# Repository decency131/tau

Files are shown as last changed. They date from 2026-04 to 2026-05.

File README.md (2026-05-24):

# tau



tau is a pedal that converts musical instrument input into USB MIDI notes.

It is based on [daisy seed by Electrosmith](https://daisy.audio/hardware/Seed/) and [daisy-embassy](https://github.com/daisy-embassy/daisy-embassy) (which is based on [embassy](https://embassy.dev/), an embedded async runtime).

Current main branch contains firmware for the first revision hardware. Firmware for the second revision can be found on the [rev2-attempt branch](https://github.com/decency131/tau/tree/rev2-attempt) and is mostly finished, apart from optimization work currently present on the main branch. Second revision hardware needs some adjustments and fixes that are planned to be implemented in the future.

## Current features 

- Real-time pitch detection from instrument input
- USB MIDI output
- MIDI note on/off generation based on detected pitch
- Channel selection using an expression pedal
- Basic MIDI looper functionality
- Footswitch control:
  - SW1: record / play / overdub
  - SW2 short press: pause / resume
  - SW2 long press: clear loop
- Channel indicator LEDs

## How it works

The audio input is received from the Daisy Seed audio codec. Audio frames are copied from the audio callback into a separate pitch detection task, so heavier DSP work does not run directly inside the audio callback.

Pitch detection is done using a [no-std YIN implementation](https://github.com/decency131/yin-no_std). Detected frequencies are converted to MIDI notes. A small smoothing layer is used to reduce note flicker and avoid fast retriggering when the detected note is unstable.

MIDI events are sent over USB MIDI. The looper records MIDI events together with their timing and MIDI channel, so previously recorded loops keep playing on the original channel even if the expression pedal changes the current channel later.

## Build
```zsh
cargo build --features=seed_1_2 --release
```
Adjust to your seed revision.

## Flash/run

The recommended way is to use a debug probe (such as ST-LINK v3 minie), and run
```zsh 
cargo run --features=seed_1_2 --release
```
or 
```zsh 
DEFMT_LOG=warn cargo run --features=seed_1_2 --release
```
for less logging overhead.

Electrosmith have, however, recently [made their bootloader open source](https://github.com/electro-smith/DaisyBootloader), so you could try using that, or their [online flasher](https://flash.daisy.audio/).

> [!NOTE]
> This project is released under the **WTFPL** license.

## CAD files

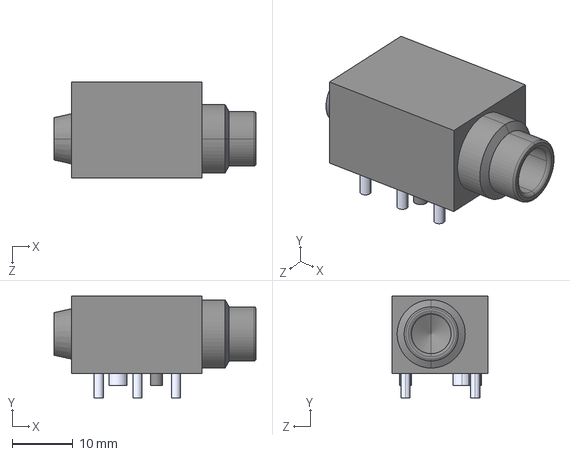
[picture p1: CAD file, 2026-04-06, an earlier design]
hw/tau_v1/3d models/NRJ6HH--3DModel-STEP-510211.STEP
33.2 x 16.7 x 15.8 mm

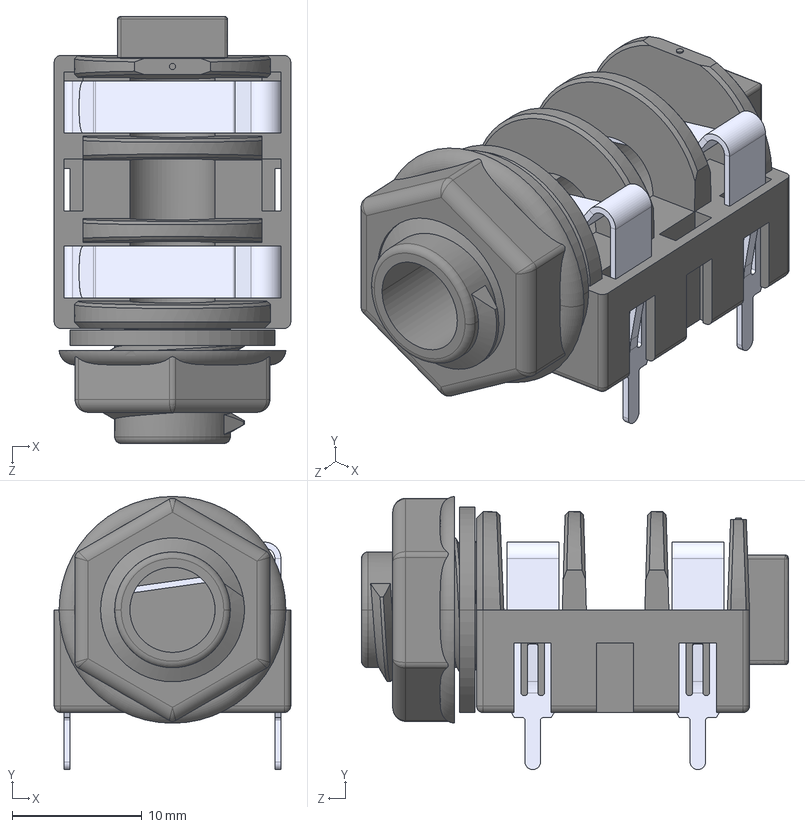
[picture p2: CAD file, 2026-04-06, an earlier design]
hw/tau_v1/3d models/NMJ4HFD2--3DModel-STEP-56544.STEP
18.2 x 21.0 x 32.9 mm

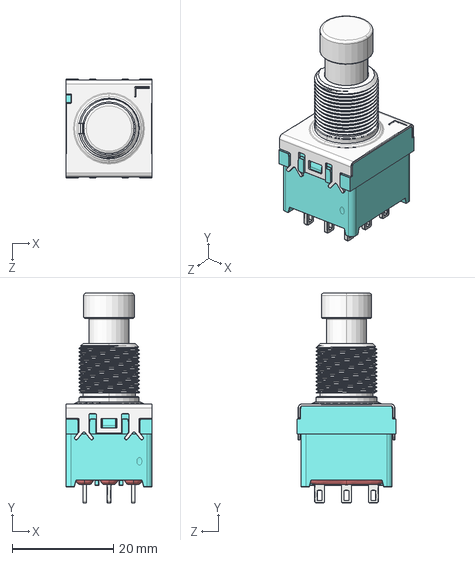
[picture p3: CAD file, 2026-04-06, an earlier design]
hw/tau_v1/3d models/3PDT_FOOTSWITCH.STEP
17.1 x 41.5 x 19.6 mm

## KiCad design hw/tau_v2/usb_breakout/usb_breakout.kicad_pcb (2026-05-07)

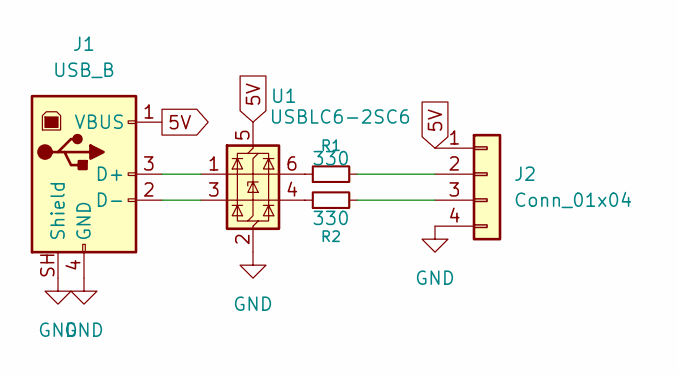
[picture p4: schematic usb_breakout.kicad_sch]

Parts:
J1: USB_B; USB_B_OST_USB-B1HSxx_Horizontal
J2: Conn_01x04; PinHeader_1x04_P2.00mm_Vertical
R1, R2: 330; R_0805_2012Metric_Pad1.20x1.40mm_HandSolder
U1: USBLC6-2SC6; SOT-23-6

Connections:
5V: J1.1 (VBUS), J2.1, U1.5 (VBUS)
GND: J1.4 (GND), J1.SH (Shield), J2.4, U1.2 (GND)
unnamed: J1.3 (D+), U1.1 (I/O1)
unnamed: J1.2 (D-), U1.3 (I/O2)
unnamed: J2.2, R1.2
unnamed: J2.3, R2.2
unnamed: R1.1, U1.6 (I/O1)
unnamed: R2.1, U1.4 (I/O2)

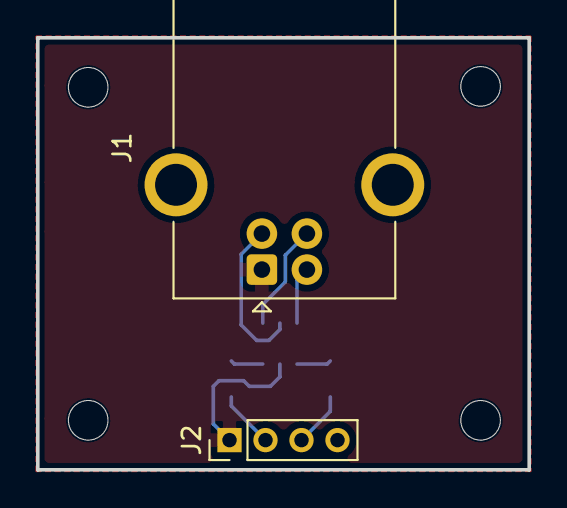
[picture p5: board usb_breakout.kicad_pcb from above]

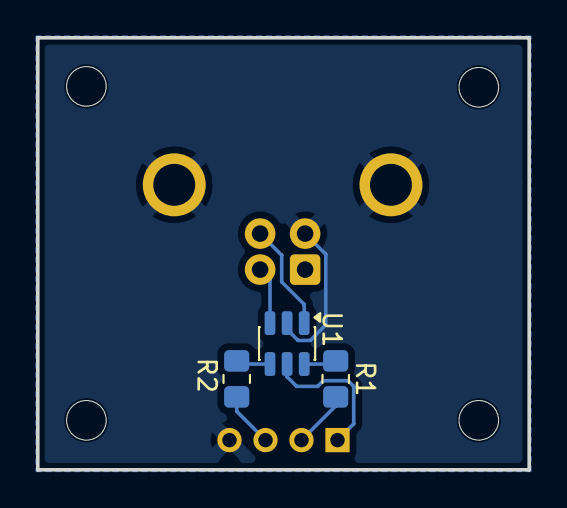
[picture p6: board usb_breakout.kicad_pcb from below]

Board: 2 copper layers, 27.3 x 24.0 mm, 9 parts (3 on the bottom side), 8 nets.

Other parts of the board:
M1, M2, M3, M4: MountingHole_2.2mm_M2

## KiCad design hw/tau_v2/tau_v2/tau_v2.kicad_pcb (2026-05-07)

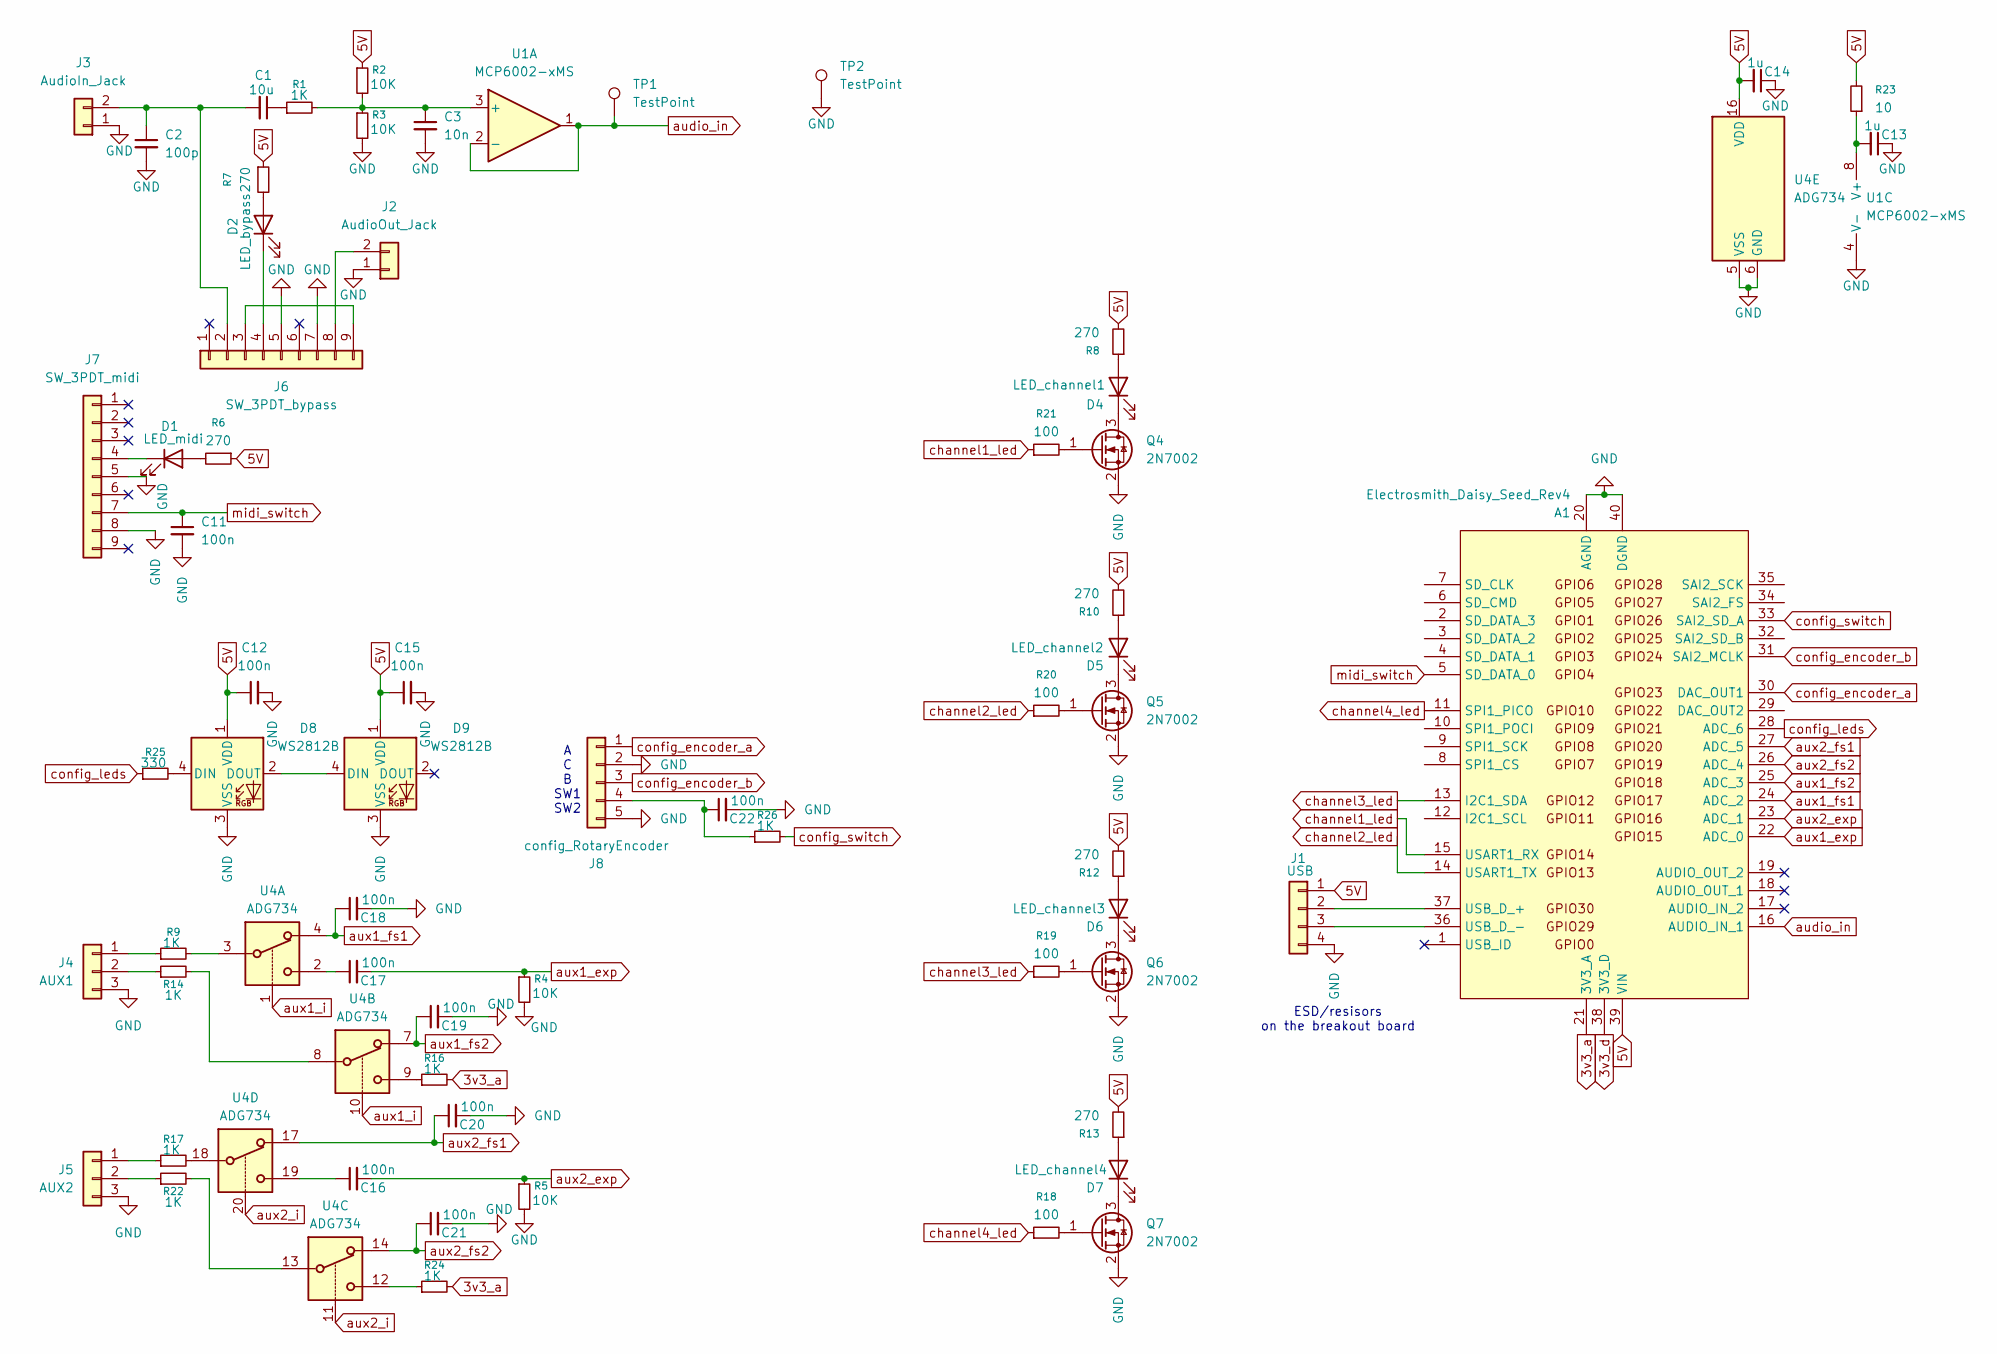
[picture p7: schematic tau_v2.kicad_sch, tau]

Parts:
A1: Electrosmith_Daisy_Seed_Rev4; Electrosmith_Daisy_Seed
C1: 10u; C_0805_2012Metric_Pad1.18x1.45mm_HandSolder
C2: 100p; C_0805_2012Metric_Pad1.18x1.45mm_HandSolder
C3: 10n; C_0805_2012Metric_Pad1.18x1.45mm_HandSolder
C11, C12, C15, C16, C17, C18, C19, C20, C21, C22: 100n; C_0805_2012Metric_Pad1.18x1.45mm_HandSolder
C13, C14: 1u; C_0805_2012Metric_Pad1.18x1.45mm_HandSolder
D1: LED_midi; PinHeader_1x02_P2.00mm_Vertical
D2: LED_bypass; PinHeader_1x02_P2.00mm_Vertical
D4: LED_channel1; PinHeader_1x02_P2.00mm_Vertical
D5: LED_channel2; PinHeader_1x02_P2.00mm_Vertical
D6: LED_channel3; PinHeader_1x02_P2.00mm_Vertical
D7: LED_channel4; PinHeader_1x02_P2.00mm_Vertical
D8, D9: WS2812B; PinHeader_1x04_P2.00mm_Vertical
J1: USB; PinHeader_1x04_P2.00mm_Vertical
J2: AudioOut_Jack; PinHeader_1x02_P2.00mm_Vertical
J3: AudioIn_Jack; PinHeader_1x02_P2.00mm_Vertical
J4: AUX1; PinHeader_1x03_P2.00mm_Vertical
J5: AUX2; PinHeader_1x03_P2.00mm_Vertical
J6: SW_3PDT_bypass; PinHeader_1x09_P2.00mm_Vertical
J7: SW_3PDT_midi; PinHeader_1x09_P2.00mm_Vertical
J8: config_RotaryEncoder; PinHeader_1x05_P2.00mm_Vertical
Q4, Q5, Q6, Q7: 2N7002; SOT-23
R1, R9, R14, R16, R17, R22, R24, R26: 1K; R_0805_2012Metric_Pad1.20x1.40mm_HandSolder
R2, R3, R4, R5: 10K; R_0805_2012Metric_Pad1.20x1.40mm_HandSolder
R6, R7, R8, R10, R12, R13: 270; R_0805_2012Metric_Pad1.20x1.40mm_HandSolder
R18, R19, R20, R21: 100; R_0805_2012Metric_Pad1.20x1.40mm_HandSolder
R23: 10; R_0805_2012Metric_Pad1.20x1.40mm_HandSolder
R25: 330; R_0805_2012Metric_Pad1.20x1.40mm_HandSolder
TP1, TP2: TestPoint; Pin_D1.0mm_L10.0mm_LooseFit
U1: MCP6002-xMS; MSOP-8-1EP_3x3mm_P0.65mm_EP1.5x1.8mm_handsoldered
U4: ADG734; TSSOP-20_4.4x6.5mm_P0.65mm

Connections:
3v3_a: A1.21 (3V3_A), R16.2, R24.2
3v3_d: A1.38 (3V3_D)
5V: A1.39 (VIN), C12.1, C14.2, C15.1, D8.1 (VDD), D9.1 (VDD), J1.1, R2.1, R6.1, R7.1, R8.2, R10.2, R12.2, R13.2, R23.2, U4.16 (VDD)
GND: A1.20 (AGND), A1.40 (DGND), C2.2, C3.2, C11.2, C12.2, C13.1, C14.1, C15.2, C18.2, C19.2, C20.2, C21.2, C22.2, D8.3 (VSS), D9.3 (VSS), J1.4, J2.1, J3.1, J4.3, J5.3, J6.5, J6.7, J7.5, J7.8, J8.2, J8.5, Q4.2 (S), Q5.2 (S), Q6.2 (S), Q7.2 (S), R3.2, R4.2, R5.2, TP2.1 (1_1), U1.4 (V-), U4.5 (VSS), U4.6 (GND)
unnamed: A1.37 (USB_D_+), J1.2
unnamed: A1.36 (USB_D_-), J1.3
unnamed: C1.1, R1.1
unnamed: C16.1, U4.19
unnamed: C17.1, U4.2
unnamed: D1.2 (A), R6.2
unnamed: D1.1 (K), J7.4
unnamed: D2.2 (A), R7.2
unnamed: D2.1 (K), J6.4
unnamed: D4.2 (A), R8.1
unnamed: D4.1 (K), Q4.3 (D)
unnamed: D5.2 (A), R10.1
unnamed: D5.1 (K), Q5.3 (D)
unnamed: D6.2 (A), R12.1
unnamed: D6.1 (K), Q6.3 (D)
unnamed: D7.2 (A), R13.1
unnamed: D7.1 (K), Q7.3 (D)
unnamed: D8.4 (DIN), R25.2
unnamed: D8.2 (DOUT), D9.4 (DIN)
unnamed: J2.2, J6.8
unnamed: C1.2, C2.1, J3.2, J6.2
unnamed: J4.1, R9.1
unnamed: J4.2, R14.1
unnamed: J5.1, R17.1
unnamed: J5.2, R22.1
unnamed: J6.3, J6.9
unnamed: C22.1, J8.4, R26.1
unnamed: Q4.1 (G), R21.2
unnamed: Q5.1 (G), R20.2
unnamed: Q6.1 (G), R19.2
unnamed: Q7.1 (G), R18.2
unnamed: R9.2, U4.3
unnamed: R14.2, U4.8
unnamed: R16.1, U4.9
unnamed: R17.2, U4.18
unnamed: R22.2, U4.13
unnamed: R24.1, U4.12
unnamed: C3.1, R1.2, R2.2, R3.1, U1.3 (+)
unnamed: C13.2, R23.1, U1.8 (V+)
audio_in: A1.16 (AUDIO_IN_1), TP1.1 (1_1), U1.1, U1.2 (-)
aux1_exp: A1.22 (ADC_0), C17.2, R4.1
aux1_fs1: A1.24 (ADC_2), C18.1, U4.4
aux1_fs2: A1.25 (ADC_3), C19.1, U4.7
aux1_i: U4.1, U4.10
aux2_exp: A1.23 (ADC_1), C16.2, R5.1
aux2_fs1: A1.27 (ADC_5), C20.1, U4.17
aux2_fs2: A1.26 (ADC_4), C21.1, U4.14
aux2_i: U4.11, U4.20
channel1_led: A1.15 (USART1_RX), R21.1
channel2_led: A1.14 (USART1_TX), R20.1
channel3_led: A1.13 (I2C1_SDA), R19.1
channel4_led: A1.11 (SPI1_PICO), R18.1
config_encoder_a: A1.30 (DAC_OUT1), J8.1
config_encoder_b: A1.31 (SAI2_MCLK), J8.3
config_leds: A1.28 (ADC_6), R25.1
config_switch: A1.33 (SAI2_SD_A), R26.2
midi_switch: A1.5 (SD_DATA_0), C11.1, J7.7

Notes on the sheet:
ESD/resisors on the breakout board
A C B SW1 SW2

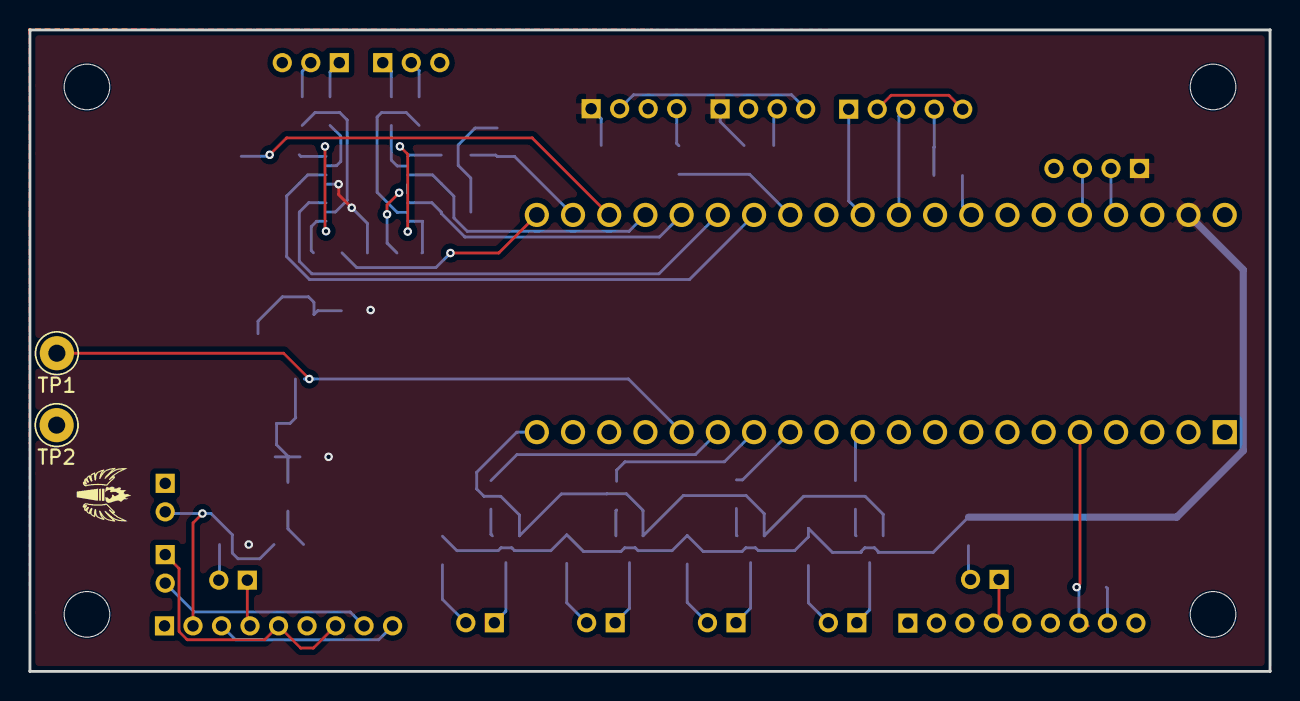
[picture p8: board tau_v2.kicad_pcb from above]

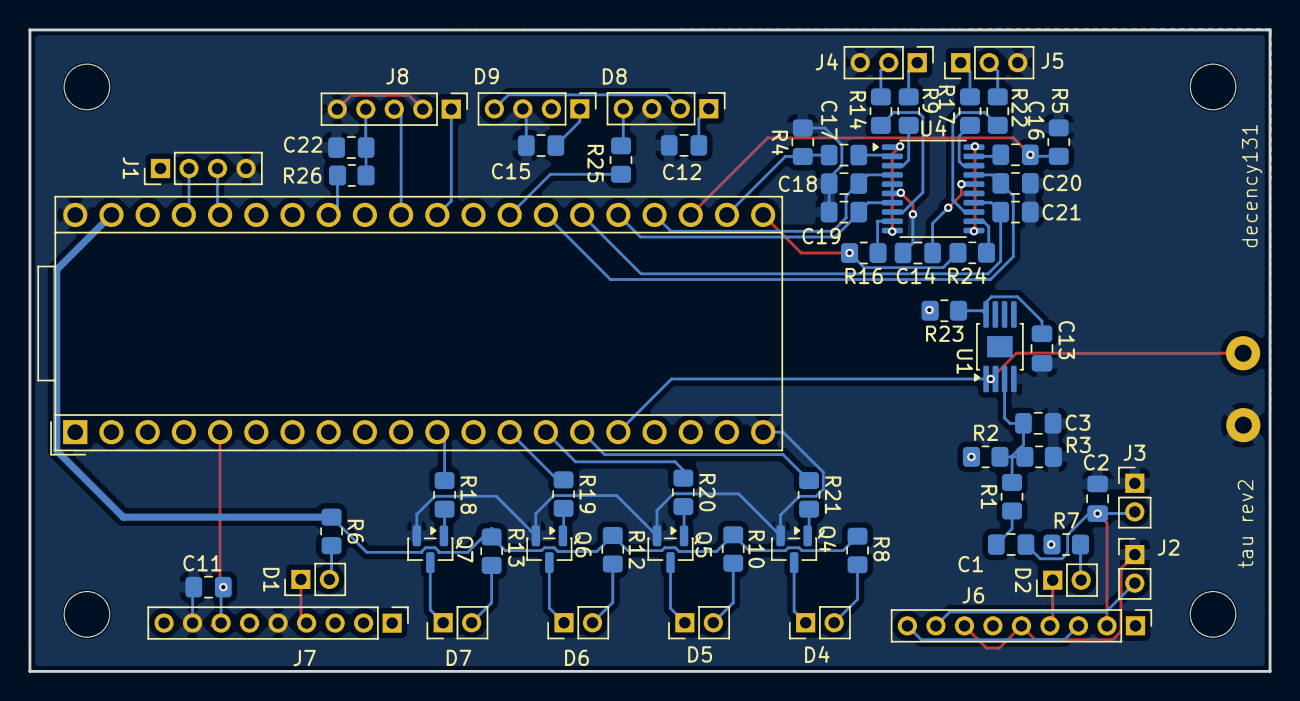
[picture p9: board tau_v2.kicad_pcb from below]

Board: 2 copper layers, 87.0 x 45.0 mm, 68 parts (62 on the bottom side), 60 nets.

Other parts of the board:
MH1, MH2, MH3, MH4: MountingHole_3.2mm_M3

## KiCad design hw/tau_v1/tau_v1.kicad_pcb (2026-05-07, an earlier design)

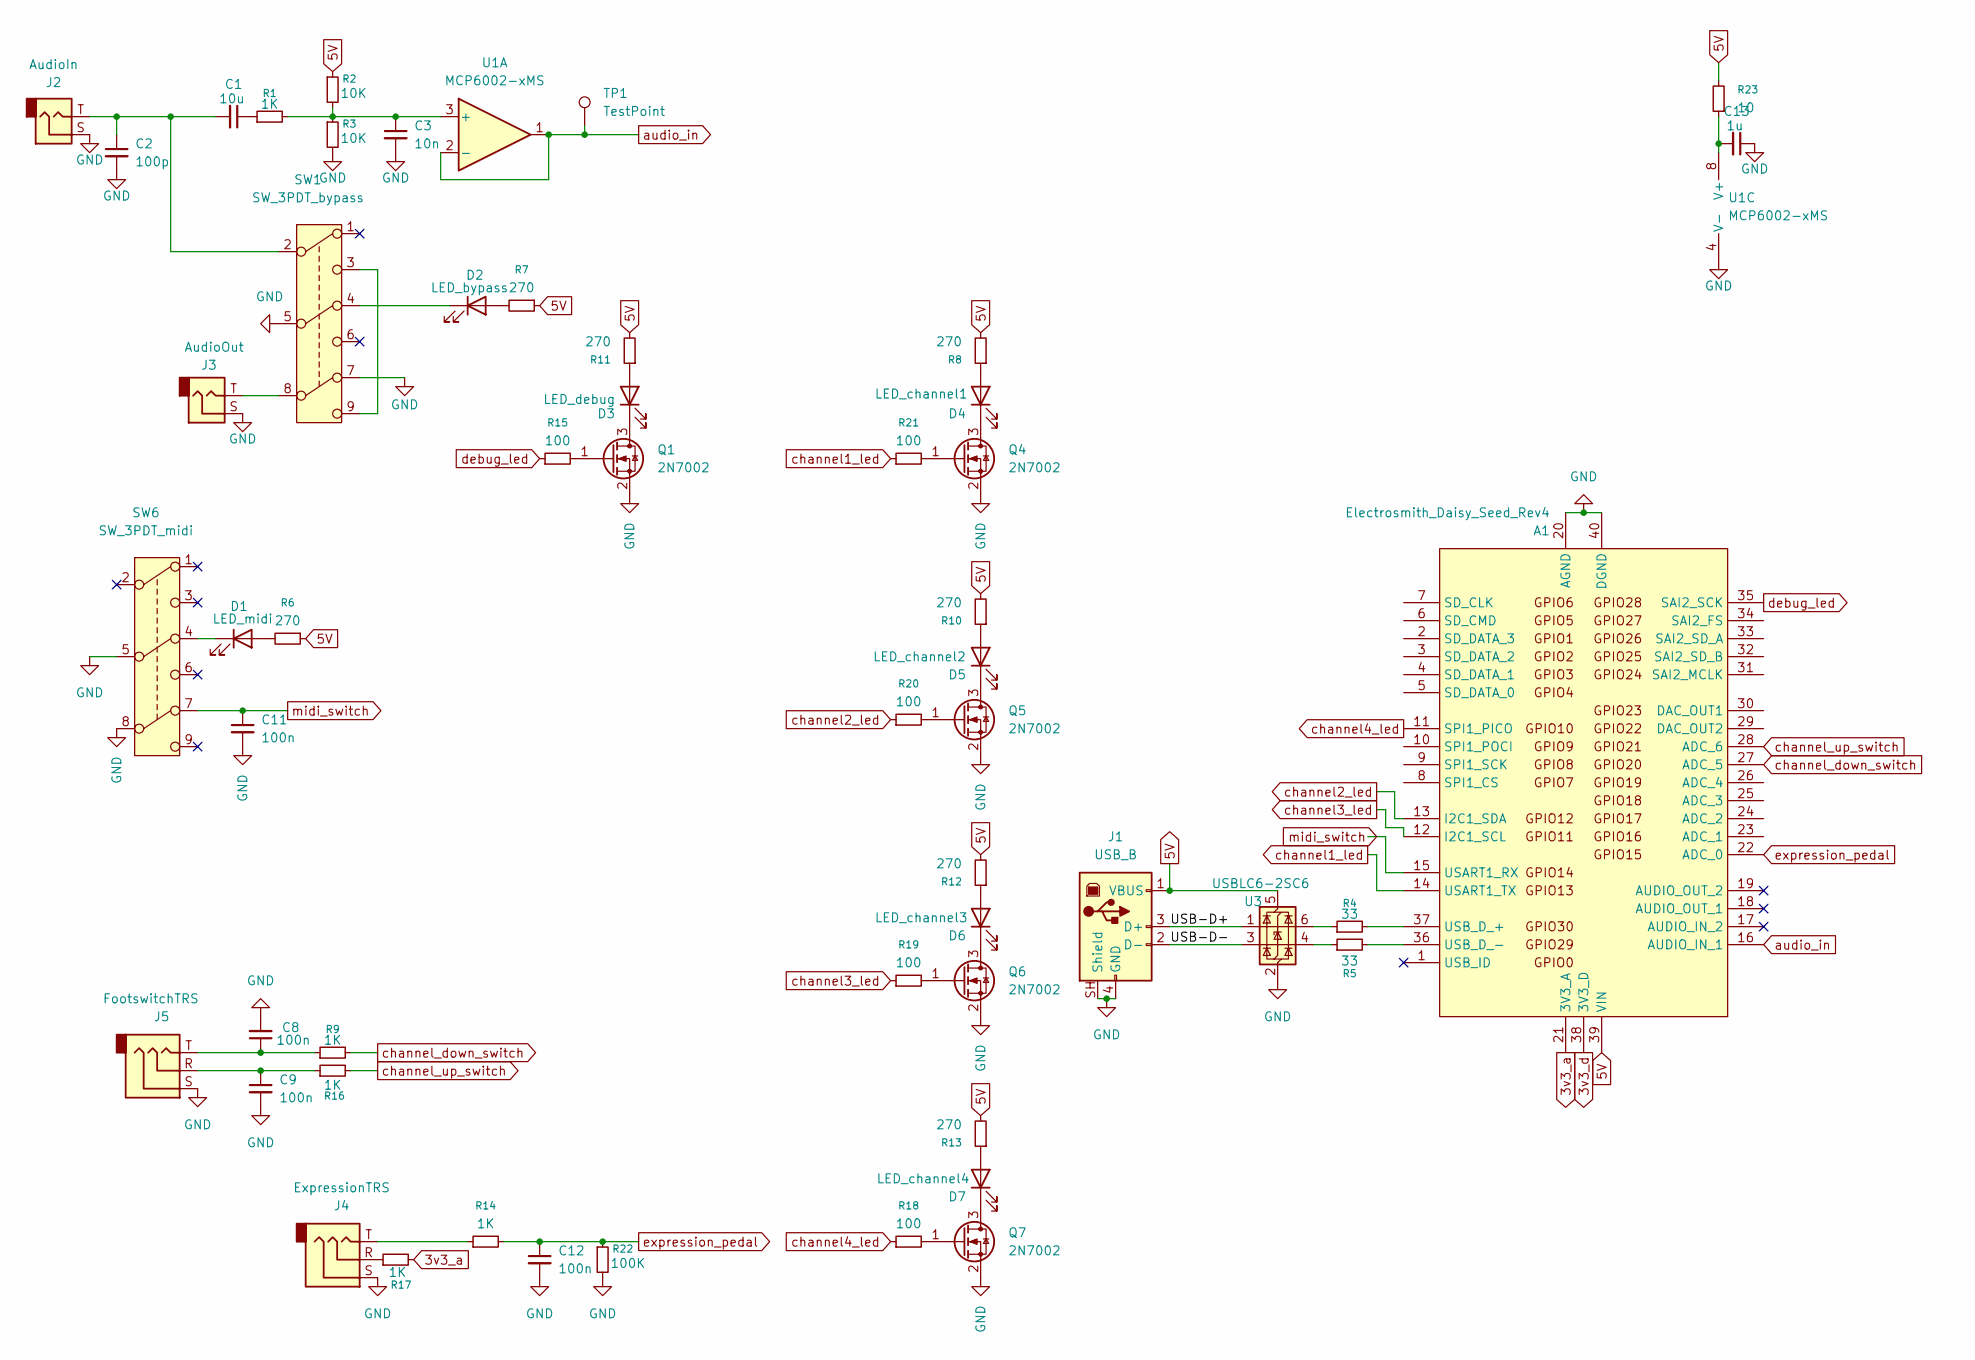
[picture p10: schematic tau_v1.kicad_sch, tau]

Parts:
A1: Electrosmith_Daisy_Seed_Rev4; Electrosmith_Daisy_Seed
C1: 10u; C_0805_2012Metric_Pad1.18x1.45mm_HandSolder
C2: 100p; C_0805_2012Metric_Pad1.18x1.45mm_HandSolder
C3: 10n; C_0805_2012Metric_Pad1.18x1.45mm_HandSolder
C8, C9, C11, C12: 100n; C_0805_2012Metric_Pad1.18x1.45mm_HandSolder
C13: 1u; C_0805_2012Metric_Pad1.18x1.45mm_HandSolder
D1: LED_midi; JST_XH_B2B-XH-A_1x02_P2.50mm_Vertical
D2: LED_bypass; JST_XH_B2B-XH-A_1x02_P2.50mm_Vertical
D3: LED_debug; LED_0805_2012Metric_Pad1.15x1.40mm_HandSolder
D4: LED_channel1; JST_XH_B2B-XH-A_1x02_P2.50mm_Vertical
D5: LED_channel2; JST_XH_B2B-XH-A_1x02_P2.50mm_Vertical
D6: LED_channel3; JST_XH_B2B-XH-A_1x02_P2.50mm_Vertical
D7: LED_channel4; JST_XH_B2B-XH-A_1x02_P2.50mm_Vertical
J1: USB_B; USB_B_OST_USB-B1HSxx_Horizontal
J2: AudioIn; Jack_6.35mm_Neutrik_NMJ4HFD2_Horizontal
J3: AudioOut; Jack_6.35mm_Neutrik_NMJ4HFD2_Horizontal
J4: ExpressionTRS; Jack_6.35mm_Neutrik_NRJ6HH-AU_Horizontal
J5: FootswitchTRS; Jack_6.35mm_Neutrik_NRJ6HH-AU_Horizontal
Q1, Q4, Q5, Q6, Q7: 2N7002; SOT-23
R1, R9, R14, R16, R17: 1K; R_0805_2012Metric_Pad1.20x1.40mm_HandSolder
R2, R3: 10K; R_0805_2012Metric_Pad1.20x1.40mm_HandSolder
R4, R5: 33; R_0805_2012Metric_Pad1.20x1.40mm_HandSolder
R6, R7, R8, R10, R11, R12, R13: 270; R_0805_2012Metric_Pad1.20x1.40mm_HandSolder
R15, R18, R19, R20, R21: 100; R_0805_2012Metric_Pad1.20x1.40mm_HandSolder
R22: 100K; R_0805_2012Metric_Pad1.20x1.40mm_HandSolder
R23: 10; R_0805_2012Metric_Pad1.20x1.40mm_HandSolder
SW1: SW_3PDT_bypass; SW_3PDT
SW6: SW_3PDT_midi; SW_3PDT
TP1: TestPoint; Pin_D1.0mm_L10.0mm_LooseFit
U1: MCP6002-xMS; MSOP-8-1EP_3x3mm_P0.65mm_EP1.5x1.8mm_handsoldered
U3: USBLC6-2SC6; SOT-23-6

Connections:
3v3_a: A1.21 (3V3_A), R17.2
3v3_d: A1.38 (3V3_D)
5V: A1.39 (VIN), J1.1 (VBUS), R2.1, R6.1, R7.1, R8.2, R10.2, R11.2, R12.2, R13.2, R23.2, U3.5 (VBUS)
/USB-D+: J1.3 (D+), U3.1 (I/O1)
/USB-D-: J1.2 (D-), U3.3 (I/O2)
GND: A1.20 (AGND), A1.40 (DGND), C2.2, C3.2, C8.2, C9.2, C11.2, C12.2, C13.1, J1.4 (GND), J1.SH (Shield), J2.S, J3.S, J4.S, J5.S, Q1.2 (S), Q4.2 (S), Q5.2 (S), Q6.2 (S), Q7.2 (S), R3.2, R22.2, SW1.5, SW1.7, SW6.5, SW6.8, U1.4 (V-), U3.2 (GND)
unnamed: A1.37 (USB_D_+), R4.2
unnamed: A1.36 (USB_D_-), R5.2
unnamed: C1.1, R1.1
unnamed: C1.2, C2.1, J2.T, SW1.2
unnamed: C8.1, J5.T, R9.1
unnamed: C9.1, J5.R, R16.1
unnamed: D1.2 (A), R6.2
unnamed: D1.1 (K), SW6.4
unnamed: D2.2 (A), R7.2
unnamed: D2.1 (K), SW1.4
unnamed: D3.2 (A), R11.1
unnamed: D3.1 (K), Q1.3 (D)
unnamed: D4.2 (A), R8.1
unnamed: D4.1 (K), Q4.3 (D)
unnamed: D5.2 (A), R10.1
unnamed: D5.1 (K), Q5.3 (D)
unnamed: D6.2 (A), R12.1
unnamed: D6.1 (K), Q6.3 (D)
unnamed: D7.2 (A), R13.1
unnamed: D7.1 (K), Q7.3 (D)
unnamed: J3.T, SW1.8
unnamed: J4.R, R17.1
unnamed: J4.T, R14.1
unnamed: Q1.1 (G), R15.2
unnamed: Q4.1 (G), R21.2
unnamed: Q5.1 (G), R20.2
unnamed: Q6.1 (G), R19.2
unnamed: Q7.1 (G), R18.2
unnamed: R4.1, U3.6 (I/O1)
unnamed: R5.1, U3.4 (I/O2)
unnamed: SW1.3, SW1.9
unnamed: C3.1, R1.2, R2.2, R3.1, U1.3 (+)
unnamed: C13.2, R23.1, U1.8 (V+)
audio_in: A1.16 (AUDIO_IN_1), TP1.1 (1_1), U1.1, U1.2 (-)
channel1_led: A1.14 (USART1_TX), R21.1
channel2_led: A1.13 (I2C1_SDA), R20.1
channel3_led: A1.12 (I2C1_SCL), R19.1
channel4_led: A1.11 (SPI1_PICO), R18.1
channel_down_switch: A1.27 (ADC_5), R9.2
channel_up_switch: A1.28 (ADC_6), R16.2
debug_led: A1.35 (SAI2_SCK), R15.1
expression_pedal: A1.22 (ADC_0), C12.1, R14.2, R22.1
midi_switch: A1.15 (USART1_RX), C11.1, SW6.7

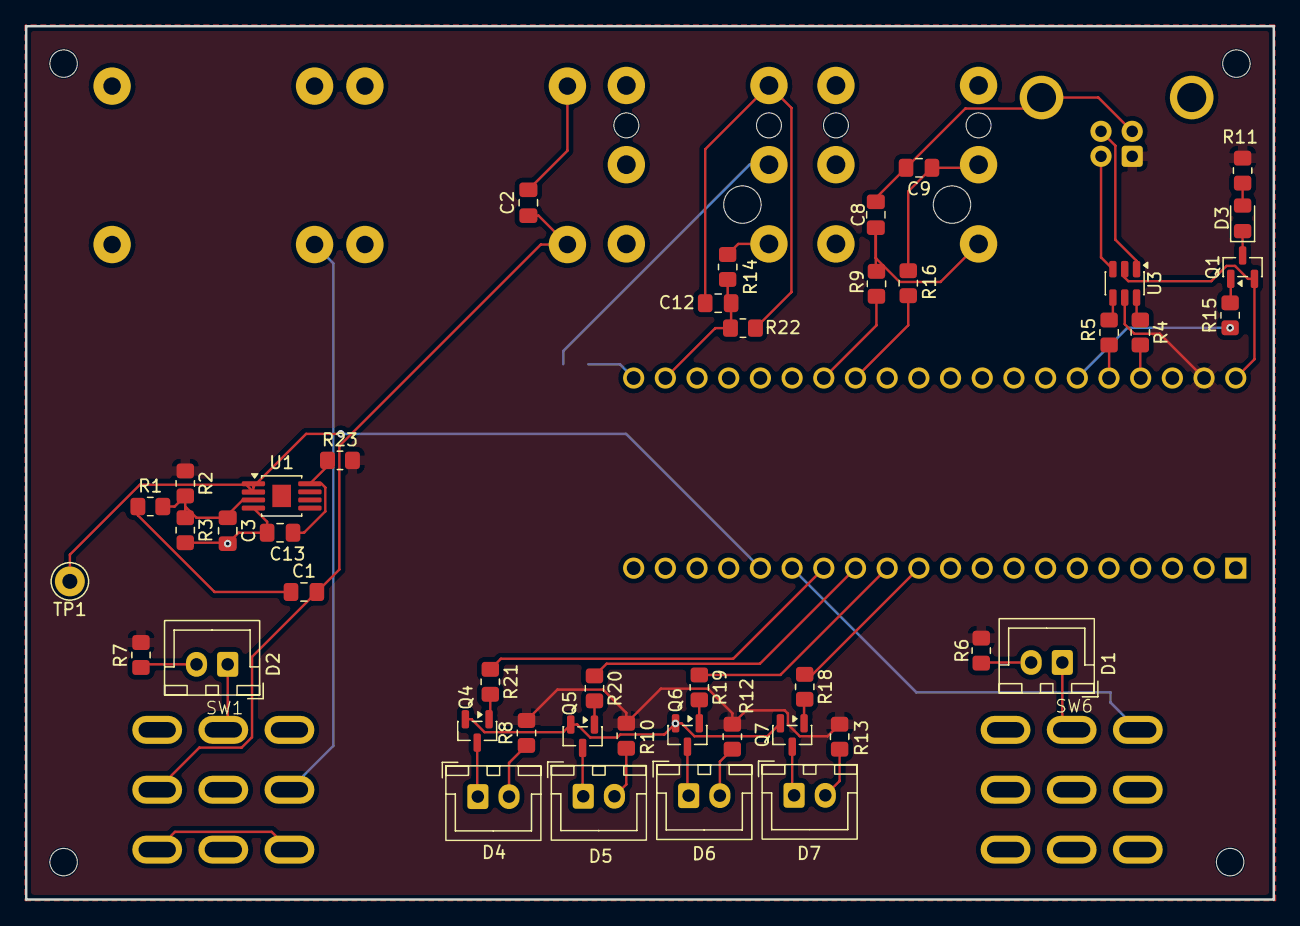
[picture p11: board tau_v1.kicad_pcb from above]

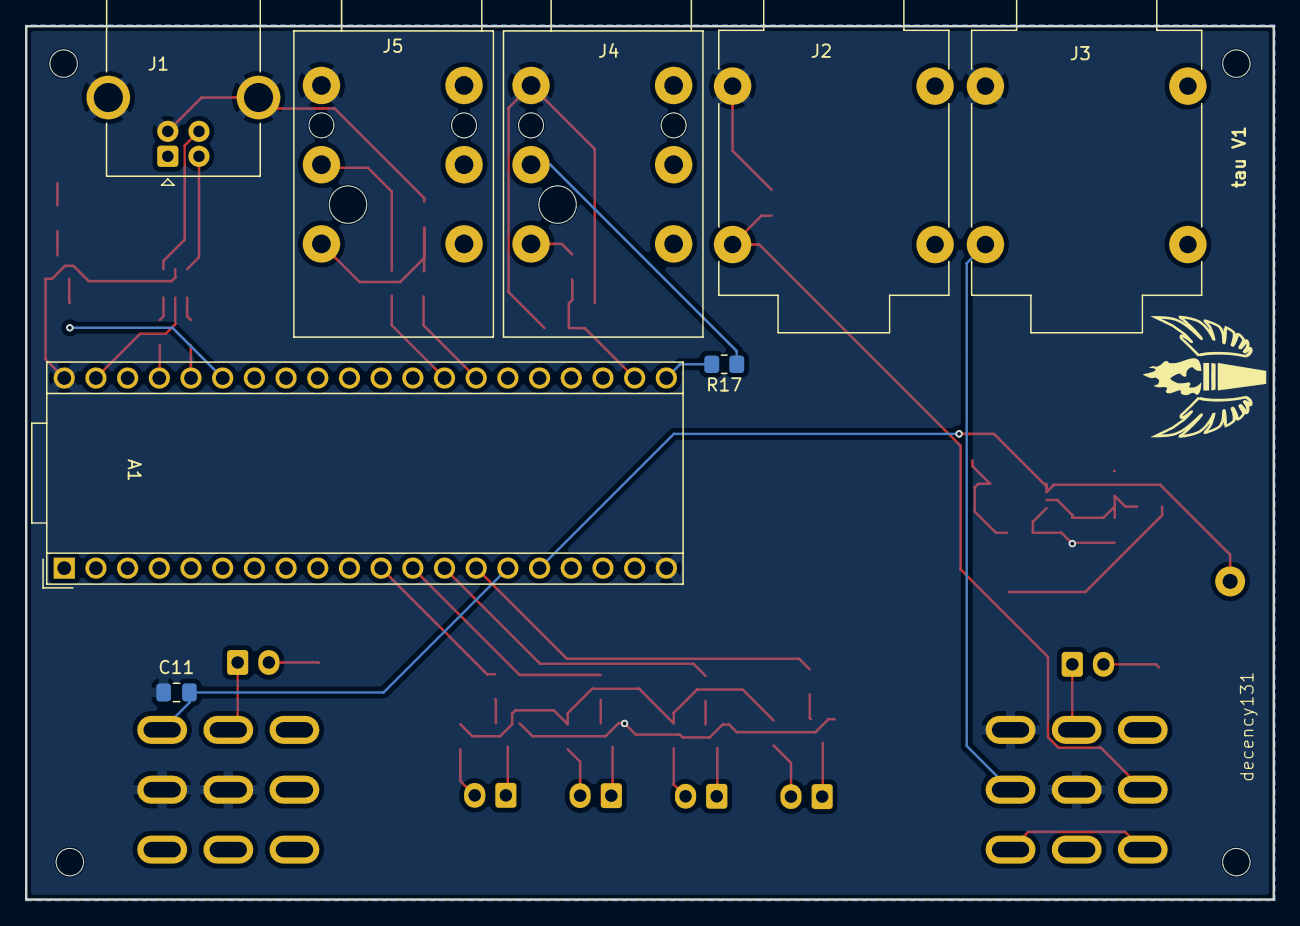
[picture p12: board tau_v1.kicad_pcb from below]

Board: 2 copper layers, 100.0 x 70.0 mm, 58 parts (8 on the bottom side), 48 nets.

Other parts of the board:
MH1, MH2, MH3, MH4: MountingHole_2.2mm_M2

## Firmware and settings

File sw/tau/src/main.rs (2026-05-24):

#![no_std]
#![no_main]

mod audio;
mod board;
mod config;
mod dsp;
mod midi;
mod utils;

use cortex_m::peripheral::Peripherals;
use daisy_embassy::{
    hal::{self, bind_interrupts, peripherals, usb},
    led::UserLed,
    new_daisy_board,
};
use defmt::{info, unwrap};
use embassy_executor::Spawner;
use embassy_futures::join::join;
use embassy_stm32::adc::Adc;
use embassy_stm32::interrupt::{InterruptExt, Priority};
use embassy_stm32::usb::{Config, Driver};
use embassy_stm32::interrupt;
use embassy_sync::{blocking_mutex::raw::CriticalSectionRawMutex, mutex::Mutex};
use embassy_time::Timer;
use embassy_usb::Builder;
use embassy_usb::class::midi::MidiClass;
use static_cell::StaticCell;
use {defmt_rtt as _, panic_probe as _};

use crate::audio::input::{AUDIO_EXECUTOR, audio_task};
use crate::config::{USB_MANUFACTURER, USB_PID, USB_PRODUCT, USB_SERIAL, USB_VID};
use crate::dsp::pitch::pitch_task;
use crate::midi::looper::looper_task;
use crate::midi::usb::usb_midi_task;

static STATE: Mutex<CriticalSectionRawMutex, board::State> = Mutex::new(board::State::new());

bind_interrupts!(pub struct UsbIrqs {
    OTG_HS => usb::InterruptHandler<peripherals::USB_OTG_HS>;
});

#[embassy_stm32::interrupt]
unsafe fn SAI1() {
    unsafe { AUDIO_EXECUTOR.on_interrupt() }
}

#[embassy_executor::task]
async fn blink(mut led: UserLed<'static>) {
    loop {
        led.on();
        Timer::after_millis(500).await;

        led.off();
        Timer::after_millis(500).await;
    }
}

#[embassy_executor::main]
async fn main(spawner: Spawner) {
    info!("==== pitch detector start ====");

    let mut cp = Peripherals::take().unwrap();
    let mut rcc_config = daisy_embassy::default_rcc();

    rcc_config.rcc.mux.adcsel = hal::pac::rcc::vals::Adcsel::PLL3_R;

    cp.SCB.enable_fpu();
    cp.SCB.enable_icache();

    let p = hal::init(rcc_config);
    let board = new_daisy_board!(p);

    let ch_leds = board::ChLeds::new(
        board.pins.d13,
        board.pins.d12,
        board.pins.d11,
        board.pins.d10,
    );

    let midi_enable = board::MIDIEnable::new(board.pins.d14);

    let adc = Adc::new(p.ADC1);
    let exp = board::AUX2::new(board.pins.d15);

    let switches = board::AUX1::new(board.pins.d20, board.pins.d21);
    let _channel = {
        let state = STATE.lock().await;
        state.channel()
    };
    spawner.spawn(blink(board.user_led)).unwrap();
    spawner
        .spawn(board::aux_task(switches, exp, adc, ch_leds))
        .unwrap();
    spawner.spawn(looper_task()).unwrap();

    spawner.spawn(pitch_task(midi_enable)).unwrap();

    let interface = board
        .audio_peripherals
        .prepare_interface(Default::default())
        .await;

    interrupt::SAI1.set_priority(Priority::P6);
    let audio_spawner = AUDIO_EXECUTOR.start(interrupt::SAI1);
    unwrap!(audio_spawner.spawn(audio_task(interface)));

    interrupt::OTG_HS.set_priority(Priority::P5);

    let mut usb_config = Config::default();
    usb_config.vbus_detection = false;

    static EP_OUT_BUFFER: StaticCell<[u8; 256]> = StaticCell::new();
    let ep_out_buffer = EP_OUT_BUFFER.init([0; 256]);

    let driver = Driver::new_fs(
        p.USB_OTG_HS,
        UsbIrqs,
        board.pins.d30,
        board.pins.d29,
        ep_out_buffer,
        usb_config,
    );

    let mut device_config = embassy_usb::Config::new(USB_VID, USB_PID);
    device_config.manufacturer = Some(USB_MANUFACTURER);
    device_config.product = Some(USB_PRODUCT);
    device_config.serial_number = Some(USB_SERIAL);
    device_config.device_class = 0xEF;
    device_config.device_sub_class = 0x02;
    device_config.device_protocol = 0x01;
    device_config.composite_with_iads = true;

    static CONFIG_DESCRIPTOR: StaticCell<[u8; 256]> = StaticCell::new();
    static BOS_DESCRIPTOR: StaticCell<[u8; 256]> = StaticCell::new();
    static CONTROL_BUF: StaticCell<[u8; 64]> = StaticCell::new();

    let config_descriptor = CONFIG_DESCRIPTOR.init([0; 256]);
    let bos_descriptor = BOS_DESCRIPTOR.init([0; 256]);
    let control_buf = CONTROL_BUF.init([0; 64]);

    let mut builder = Builder::new(
        driver,
        device_config,
        config_descriptor,
        bos_descriptor,
        &mut [],
        control_buf,
    );

    let mut midi_class = MidiClass::new(&mut builder, 1, 1, 64);
    let mut usb = builder.build();

    info!("USB MIDI ready; waiting for host");
    join(usb.run(), usb_midi_task(&mut midi_class)).await;
}

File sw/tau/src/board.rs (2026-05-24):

use crate::STATE;
use crate::config;
use crate::midi::looper::{LooperControl, queue_looper_control};

use daisy_embassy::pins::*;
use defmt::info;
use embassy_stm32::Peripheral;
use embassy_stm32::adc::{Adc, AdcChannel};
use embassy_stm32::gpio::{Input, Level, Output, Pin, Pull, Speed};
use embassy_stm32::peripherals::ADC1;
use embassy_time::{Instant, Timer};

fn expression_raw_to_channel(raw: u16, current_channel: usize) -> usize {
    let raw = raw as u32;
    let current = current_channel.min(config::EXP_CHANNELS - 1);

    let lower = current as u32 * config::EXP_ZONE_WIDTH;
    let upper = (current as u32 + 1) * config::EXP_ZONE_WIDTH;

    if current < config::EXP_CHANNELS - 1 && raw >= upper + config::EXP_HYSTERESIS {
        (raw / config::EXP_ZONE_WIDTH).min((config::EXP_CHANNELS - 1) as u32) as usize
    } else if current > 0 && raw + config::EXP_HYSTERESIS < lower {
        (raw / config::EXP_ZONE_WIDTH).min((config::EXP_CHANNELS - 1) as u32) as usize
    } else {
        current
    }
}

#[derive(Clone, Copy)]
pub enum SwitchEvent {
    Sw1Pressed,
    Sw1Released,
    Sw2Pressed,
    Sw2Released,
}

pub struct State {
    midi_channel: usize,
}

pub struct ChLeds {
    ch1_led: Output<'static>,
    ch2_led: Output<'static>,
    ch3_led: Output<'static>,
    ch4_led: Output<'static>,
}

pub struct MIDIEnable {
    midi_enable: Input<'static>,
}

pub struct AUX1 {
    sw1: Input<'static>,
    sw2: Input<'static>,

    sw1_was_pressed: bool,
    sw2_was_pressed: bool,
}

pub struct AUX2<PIN> {
    pin_adc: PIN,
}

impl State {
    pub const fn new() -> Self {
        Self { midi_channel: 0 }
    }

    pub fn set_channel(&mut self, channel: usize) {
        self.midi_channel = channel % 4;
    }

    pub fn channel(&self) -> usize {
        self.midi_channel
    }
}

impl AUX1 {
    pub fn new(
        sw1: impl Peripheral<P = impl Pin> + 'static,
        sw2: impl Peripheral<P = impl Pin> + 'static,
    ) -> Self {
        Self {
            sw1: Input::new(sw1, Pull::Up),
            sw2: Input::new(sw2, Pull::Up),

            sw1_was_pressed: false,
            sw2_was_pressed: false,
        }
    }

    pub fn sw1_pressed(&self) -> bool {
        self.sw1.is_low()
    }

    pub fn sw2_pressed(&self) -> bool {
        self.sw2.is_low()
    }

    pub fn poll_event(&mut self) -> Option<SwitchEvent> {
        let sw1_pressed = self.sw1_pressed();
        if sw1_pressed != self.sw1_was_pressed {
            self.sw1_was_pressed = sw1_pressed;

            return Some(if sw1_pressed {
                SwitchEvent::Sw1Pressed
            } else {
                SwitchEvent::Sw1Released
            });
        }

        let sw2_pressed = self.sw2_pressed();
        if sw2_pressed != self.sw2_was_pressed {
            self.sw2_was_pressed = sw2_pressed;

            return Some(if sw2_pressed {
                SwitchEvent::Sw2Pressed
            } else {
                SwitchEvent::Sw2Released
            });
        }

        None
    }
}

impl<PIN> AUX2<PIN>
where
    PIN: AdcChannel<ADC1>,
{
    pub fn new(pin_adc: PIN) -> Self {
        Self { pin_adc }
    }

    pub fn read_raw(&mut self, adc: &mut Adc<'static, ADC1>) -> u16 {
        adc.blocking_read(&mut self.pin_adc)
    }
}

impl ChLeds {
    pub fn new(
        ch1: impl Peripheral<P = impl Pin> + 'static,
        ch2: impl Peripheral<P = impl Pin> + 'static,
        ch3: impl Peripheral<P = impl Pin> + 'static,
        ch4: impl Peripheral<P = impl Pin> + 'static,
    ) -> Self {
        Self {
            ch1_led: Output::new(ch1, Level::Low, Speed::Medium),
            ch2_led: Output::new(ch2, Level::Low, Speed::Medium),
            ch3_led: Output::new(ch3, Level::Low, Speed::Medium),
            ch4_led: Output::new(ch4, Level::Low, Speed::Medium),
        }
    }

    pub fn set_channel(&mut self, channel: usize) {
        self.ch1_led.set_low();
        self.ch2_led.set_low();
        self.ch3_led.set_low();
        self.ch4_led.set_low();

        match channel {
            0 => self.ch1_led.set_high(),
            1 => self.ch2_led.set_high(),
            2 => self.ch3_led.set_high(),
            3 => self.ch4_led.set_high(),
            _ => {}
        }
    }
}

impl MIDIEnable {
    pub fn new(sw: impl Peripheral<P = impl Pin> + 'static) -> Self {
        Self {
            midi_enable: Input::new(sw, Pull::Up),
        }
    }

    pub fn is_enabled(&self) -> bool {
        self.midi_enable.is_low()
    }
}

pub type AppExpression = AUX2<SeedPin15>;

#[embassy_executor::task]
pub async fn aux_task(
    mut aux1: AUX1,
    mut exp: AppExpression,
    mut adc: Adc<'static, ADC1>,
    mut leds: ChLeds,
) {
    let mut sw2_pressed_at: Option<Instant> = None;
    let mut last_displayed_channel: Option<usize> = None;

    loop {
        // AUX1 footswitches -> looper control.
        if let Some(event) = aux1.poll_event() {
            match event {
                SwitchEvent::Sw1Pressed => {
                    info!("sw1 pressed");
                }

                SwitchEvent::Sw1Released => {
                    info!("sw1 released");
                    queue_looper_control(LooperControl::Sw1);
                }

                SwitchEvent::Sw2Pressed => {
                    info!("sw2 pressed");
                    sw2_pressed_at = Some(Instant::now());
                }

                SwitchEvent::Sw2Released => {
                    info!("sw2 released");

                    let held_ms = sw2_pressed_at
                        .map(|t| Instant::now().duration_since(t).as_millis())
                        .unwrap_or(0);

                    sw2_pressed_at = None;

                    info!("sw2 held_ms={}", held_ms);

                    if held_ms >= 1000 {
                        queue_looper_control(LooperControl::Clear);
                    } else {
                        queue_looper_control(LooperControl::PauseResume);
                    }
                }
            }
        }

        // AUX2 expression pedal -> MIDI channel select.
        let raw = exp.read_raw(&mut adc);

        let channel = {
            let mut state = STATE.lock().await;

            let current_channel = state.channel();
            let new_channel = expression_raw_to_channel(raw, current_channel);

            if new_channel != current_channel {
                state.set_channel(new_channel);
                info!("expression channel raw={} channel={}", raw, new_channel + 1);
            }

            state.channel()
        };

        if last_displayed_channel != Some(channel) {
            leds.set_channel(channel);
            last_displayed_channel = Some(channel);
        }

        Timer::after_millis(10).await;
    }
}

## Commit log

2026-03-22 first pcb design
    [tau.kicad_pcb, tau.kicad_sch]
2026-03-29 god is dead and we killed him. new pcb.
    [tau.kicad_pcb, tau.kicad_sch]
2026-05-07 rev 2 + base software
    [3PDT_FOOTSWITCH.STEP, NMJ4HFD2--3DModel-STEP-56544.STEP, NRJ6HH--3DModel-STEP-510211.STEP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]
2026-05-08 midi enable switch
2026-05-09 could read adc
2026-05-23 who has two thumbs and is a genius? not this guy!
    - reworked midi messages
    - this should be a base and works well for syntesised instruments and
    kind of works with a real guitar
    - still needs some optimisation for use with bass guitars and in general
    lower pitch instruments
    [board.rs, main.rs]
2026-05-24 Enable MIDI detection in pitch analysisminor fixes of stuff I commented before while debugging
